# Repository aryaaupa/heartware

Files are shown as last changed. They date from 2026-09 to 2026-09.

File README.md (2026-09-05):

# heartware ♥

Heartware is being developed as a custom PCB with real-time audio playback, programmable lighting, sensing, battery power, and low-power firmware. The physical gift is intended to play a user-supplied local copy of **“The Man Who Can't Be Moved” by The Script**; the copyrighted recording is intentionally **not** distributed in this repository. This project will be used to demonstrate basic engineering principles to high schoolers. 

## Project goals

- Heart-shaped custom PCB with the electronics integrated into the board
- ESP32-S3-class embedded controller
- I²S digital audio path and Class-D speaker amplifier
- Local audio playback from flash storage
- Addressable RGB LED perimeter with audio-reactive animation
- Capacitive-touch interaction
- IMU-based pick-up / motion wake behavior
- Li-ion/LiPo battery, charging, battery monitoring, and USB-C power
- Hardware power switch and low-power states
- Debug/test points for board bring-up
- KiCad design sources, BOM, manufacturing outputs, firmware, and validation documentation

## Repository structure

```text
hardware/        KiCad board and schematic sources
firmware/        Embedded firmware and audio pipeline
manufacturing/   BOM / fabrication documentation
docs/            Architecture, bring-up, and validation notes
assets/private/  LOCAL-ONLY audio assets; ignored by Git
```

## Audio asset policy

The public repository contains no copyrighted song recording. A locally obtained audio file can be placed at:

```text
assets/private/song.wav
```

That directory is excluded by `.gitignore`. The firmware/build pipeline will be developed to preprocess and embed or stream the local asset without committing it.

## Status

**Rev A** is the initial KiCad prototype and uses a simpler XIAO ESP32-C3 + I²S amplifier architecture. **Rev B** is the planned advanced redesign described above and will replace the prototype architecture before fabrication.

> Do not fabricate Rev A yet. Footprints, power design, battery circuitry, audio chain, and Rev B architecture still require design review and DRC/ERC validation.

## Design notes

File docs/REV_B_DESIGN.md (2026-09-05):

# Heartware Rev B

Rev B turns the original musical-heart idea into a portable embedded system rather than an LED novelty board.

## Product behavior

The physical slide switch is the hard master power control. When switched on, the board performs a short warm-light boot animation and waits. Touching the central copper heart starts or stops the locally installed song. Twelve perimeter RGB LEDs animate from a precomputed audio-energy envelope so the light behavior follows the recording without spending MCU time on real-time FFT processing. Picking the heart up can wake a dim idle glow through the accelerometer, but motion never starts the song automatically.

## Hardware stack

- XIAO ESP32-S3 controller for MP3 decoding, I2S, capacitive touch, USB debug and LED control.
- MAX98357A I2S Class-D amplifier driving a 4-8 ohm miniature speaker.
- LIS3DH 3-axis accelerometer for pick-up/wake interaction.
- Twelve SK6812MINI-E RGB LEDs on the visible front perimeter.
- MCP73871 power-path charger so the LiPo can charge while the downstream product rail is physically switched off.
- TPS63031 buck-boost regulator for a stable 3.3 V logic rail across a 1-cell LiPo discharge curve.
- USB-C charge input, protected 1S LiPo, master slide switch and labeled test pads.

The board is specified as 4-layer, about 86 mm wide, with a 1.2 mm substrate. Front-facing electronics are limited to the LEDs and copper touch artwork; the controller, audio and power components live on the back.

## Why this is portfolio-grade

The repo is intended to show system architecture, PCB design, power-path reasoning, digital audio, embedded filesystem use, offline signal processing, capacitive interaction, motion sensing, low-power behavior, fabrication planning, and hardware bring-up. The audio preprocessing tool produces both a compressed local playback file and a synchronized amplitude envelope, while intentionally keeping the copyrighted recording outside Git history.

## Fabrication status

Rev B is an **engineering prototype**, not yet a released Gerber package. The placement and routing intent are implemented in KiCad, but exact fine-pitch footprints and manufacturer-specific land patterns must be audited against current datasheets before fabrication. Run KiCad ERC/DRC and complete the checklist in `docs/BRINGUP.md` before generating manufacturing outputs.

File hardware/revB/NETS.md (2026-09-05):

# Heartware Rev B signal plan

## MCU allocation

| Function | XIAO ESP32-S3 pin | Net |
|---|---|---|
| Capacitive heart electrode | D0 | `TOUCH` |
| RGB LED chain | D1 | `LED_DATA` |
| I2S bit clock | D2 | `I2S_BCLK` |
| I2S word select | D3 | `I2S_WS` |
| I2S PCM data | D4 | `I2S_DOUT` |
| I2C data | D5 | `I2C_SDA` |
| I2C clock | D6 | `I2C_SCL` |
| IMU interrupt | D7 | `IMU_INT` |

## Power domains

`VBUS_5V` is USB-C charging input only. `BAT+` is the protected 1S LiPo. The MCP73871 creates `SYS_RAW`; the slide switch creates the downstream switched rail `LED_PWR`. TPS63031 derives `3V3` for logic. The amplifier and RGB LEDs use the switched raw rail so their peak current does not pass through the 3.3 V regulator.

## Layout rules

Keep the ESP32 antenna region free of copper, battery, speaker magnet, and ground pour. Keep the I2S traces short and referenced to ground. Route speaker outputs as a close differential pair and keep them away from the touch electrode. Give each RGB LED a local 0.1 uF decoupler in the fabrication revision. The center touch electrode should have a ground keepout beneath and around it to preserve sensitivity.

## Important Rev B gate

The PCB contains deliberate prototype footprints so the mechanical composition, subsystem placement, and routing intent are editable immediately in KiCad. **Do not order this revision until the exact vendor footprints are replaced or audited against current manufacturer land-pattern drawings and KiCad ERC/DRC passes.**

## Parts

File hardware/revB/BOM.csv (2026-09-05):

Ref | Qty | Part | Suggested MPN / family | Package / form | Purpose | Prototype note
U1 | 1 | ESP32-S3 controller | Seeed XIAO ESP32-S3 | module | MP3 decode, I2S, touch, LEDs, USB debug | Back-mounted, USB accessible at edge
U2 | 1 | I2S Class-D amplifier | MAX98357A module | module | Digital audio to speaker | Module keeps Rev B hand-assemblable
U3 | 1 | LiPo charger + power-path | MCP73871-2CCI/ML | QFN-20 4x4 | Charge/load sharing | Verify charger resistor values and thermal pad
U4 | 1 | 3.3V buck-boost | TPS63031DSK | WSON-10 2.5x2.5 | Stable 3.3V rail | Use recommended 2.2uH inductor and ceramics
U5 | 1 | 3-axis accelerometer | LIS3DH | LGA-16 3x3 | Pick-up wake, motion interaction | I2C + INT1
D1-D12 | 12 | Addressable RGB LED | SK6812MINI-E | 3535 reverse/mini family | Perimeter animations | Confirm exact pin orientation before assembly
J1 | 1 | USB-C receptacle | USB2.0 Type-C power-only family | mid-mount or top-mount | Charging input | Add 5.1k CC1/CC2 Rd resistors
J2 | 1 | LiPo connector | JST-PH-2 vertical/right-angle | 2-pin | 1S LiPo | Mark polarity on silk + copper
J3 | 1 | Speaker connector | JST-PH-2 or solder pads | 2-pin | 4-8 ohm speaker | Keep output pair short
SW1 | 1 | Slide switch | SPDT SMD low-profile | SMD | Master system power | Placed at lower-left edge
SPK1 | 1 | Mini speaker | 8 ohm 1W 28-40mm | off-board | Audio output | Mount behind board or in printed stand
BAT1 | 1 | Protected LiPo | 1S 3.7V 500-1000mAh | off-board | Portable power | Use protected cell for first build

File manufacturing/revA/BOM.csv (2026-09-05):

Ref | Qty | Part | Suggested specification | Notes
U1 | 1 | Seeed Studio XIAO ESP32-C3 | 21 x 17.8 mm | MCU / flash / USB programming
U2 | 1 | MAX98357A I2S amplifier breakout | 3-5 V, mono class-D | Verify 7-pin order before assembly
D1-D5 | 5 | Warm-white LED | 3 mm through-hole | Front-facing
R1-R5 | 5 | Resistor | 220 ohm 0805 | LED current limiting
R6-R7 | 2 | Resistor | 5.1k 0805 | USB-C CC pull-down
D6 | 1 | Schottky diode | SS14 SOD-123 | Power isolation
SW1 | 1 | SPST slide switch | 2-pin / ~4 mm pad spacing | Verify footprint
J1 | 1 | USB-C receptacle | 16-pin USB2/power style | Verify exact receptacle footprint
SPK | 1 | Speaker | 8 ohm 0.5-1 W, 28-40 mm | Connect to U2 breakout

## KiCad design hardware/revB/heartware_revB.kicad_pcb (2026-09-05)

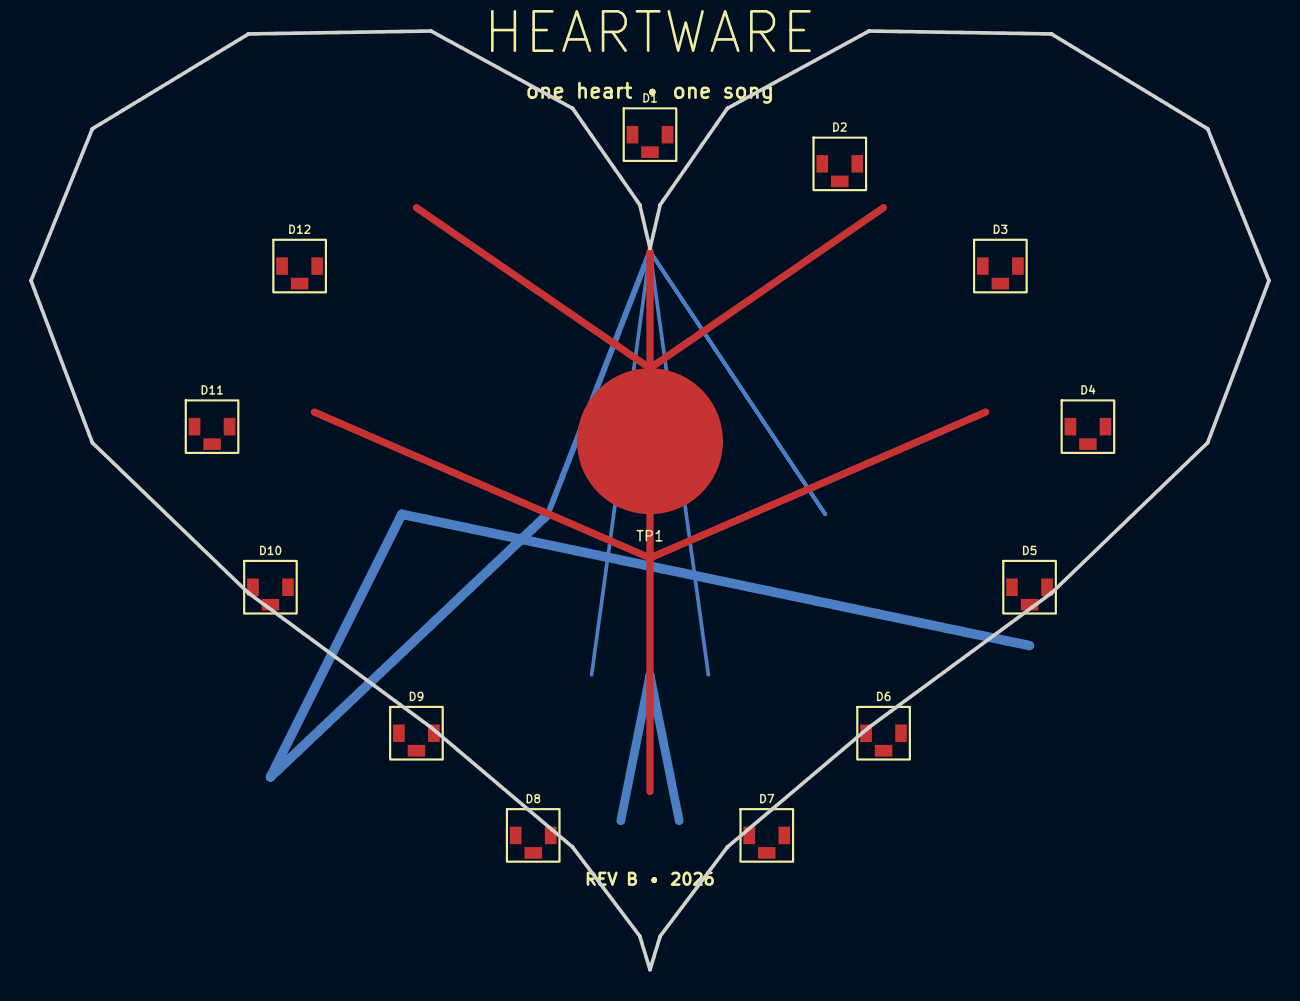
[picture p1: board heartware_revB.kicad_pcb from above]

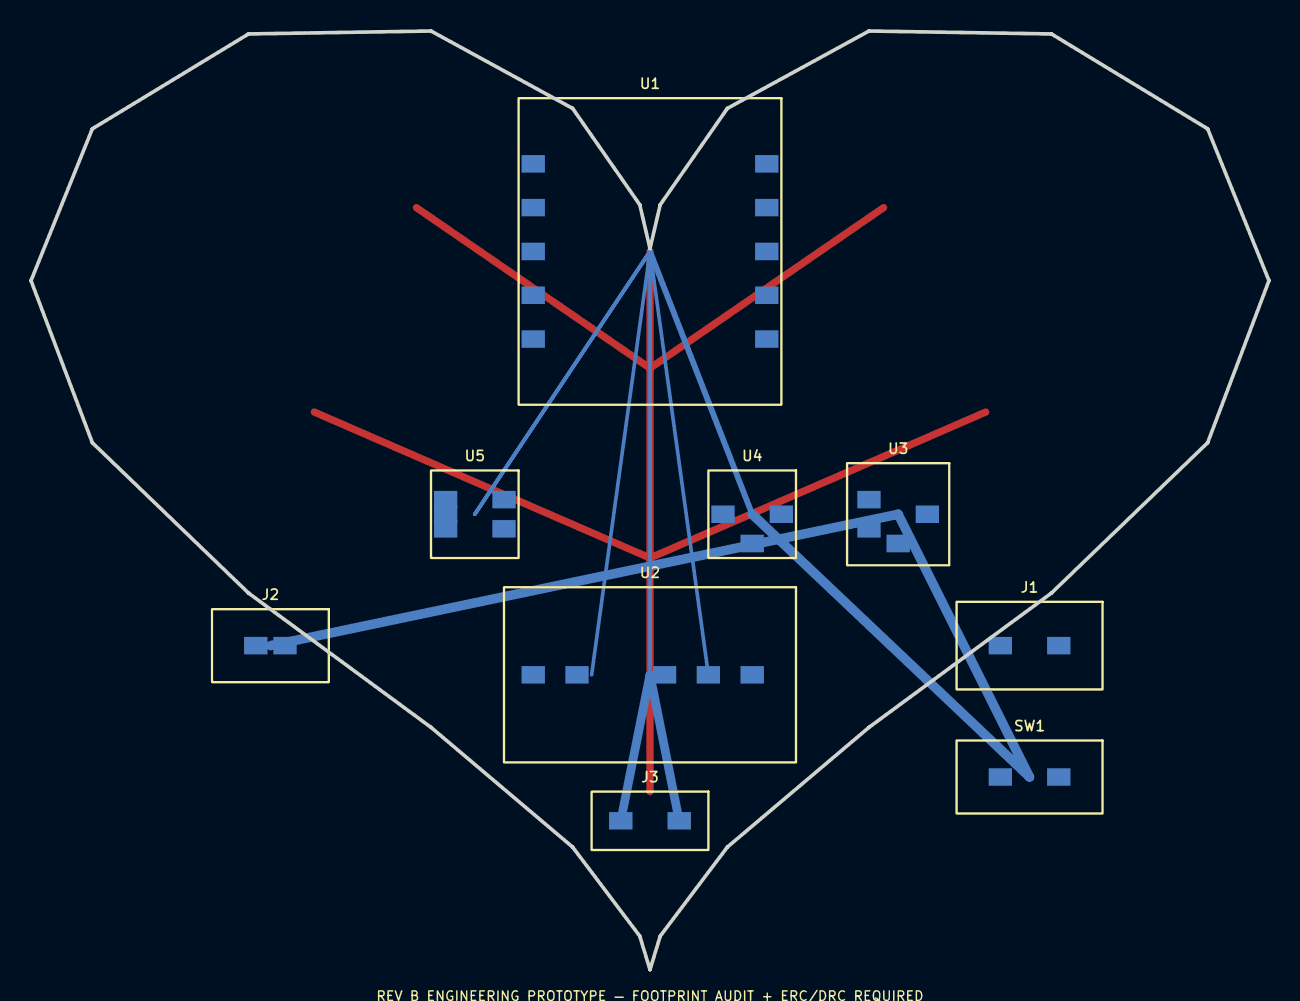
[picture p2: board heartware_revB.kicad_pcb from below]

Board: 4 copper layers, 84.8 x 64.3 mm, 22 parts (9 on the bottom side), 14 nets.

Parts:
D1: D1
D2: D2
D3: D3
D4: D4
D5: D5
D6: D6
D7: D7
D8: D8
D9: D9
D10: D10
D11: D11
D12: D12
J1: USB-C CHARGE; J1
J2: LIPO; J2
J3: SPEAKER; J3
SW1: POWER; SW1
TP1: TOUCH
U1: XIAO ESP32-S3; U1
U2: MAX98357A; U2
U3: MCP73871; U3
U4: TPS63031; U4
U5: LIS3DH; U5

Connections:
3V3: U1.3V3, U4.3V3, U5.3V3
BAT+: J2.+, U3.BAT
GND: D1.G, D2.G, D3.G, D4.G, D5.G, D6.G, D7.G, D8.G, D9.G, D10.G, D11.G, D12.G, J1.G, J2.-, U1.GND, U2.GND, U3.G, U4.G, U5.G
I2C_SCL: U1.SCL, U5.SCL
I2C_SDA: U1.SDA, U5.SDA
I2S_BCLK: U1.BCLK, U2.BCLK
I2S_DOUT: U1.DOUT, U2.DIN
I2S_WS: U1.WS, U2.WS
IMU_INT: U1.INT, U5.INT
LED_DATA: D1.D, D2.D, D3.D, D4.D, D5.D, D6.D, D7.D, D8.D, D9.D, D10.D, D11.D, D12.D, U1.LED
LED_PWR: D1.V, D2.V, D3.V, D4.V, D5.V, D6.V, D7.V, D8.V, D9.V, D10.V, D11.V, D12.V, SW1.OUT, U2.VIN, U4.IN
SYS_RAW: SW1.IN, U3.OUT
TOUCH: TP1.1, U1.TOUCH
VBUS_5V: J1.5V, U3.IN

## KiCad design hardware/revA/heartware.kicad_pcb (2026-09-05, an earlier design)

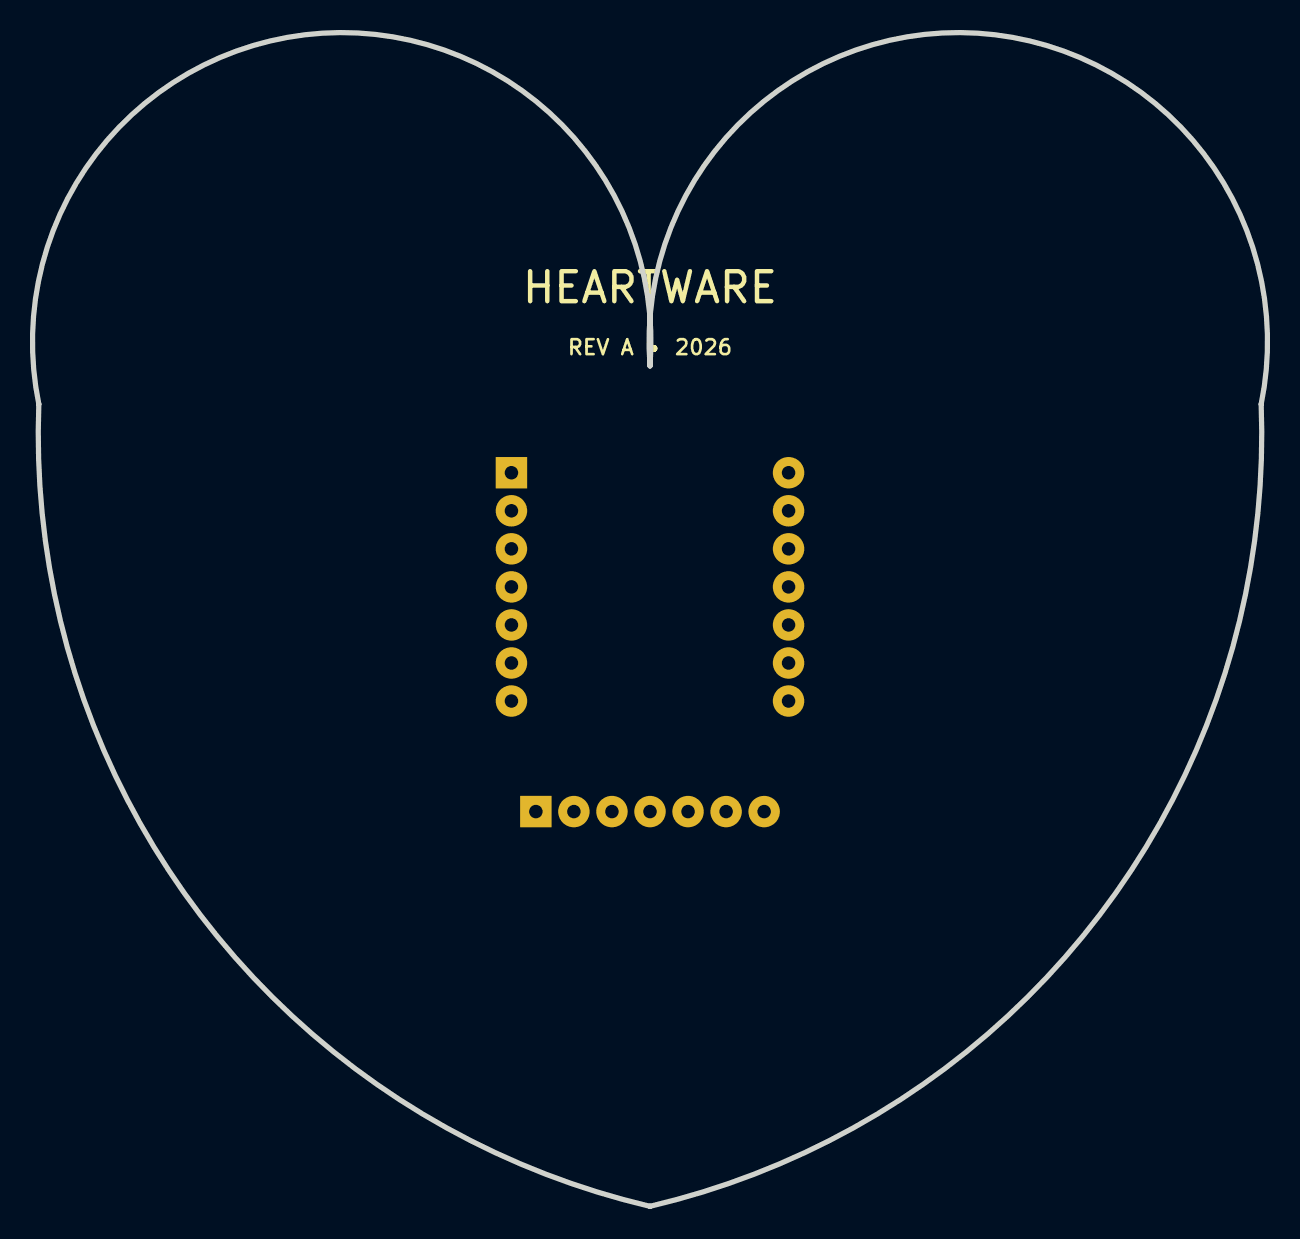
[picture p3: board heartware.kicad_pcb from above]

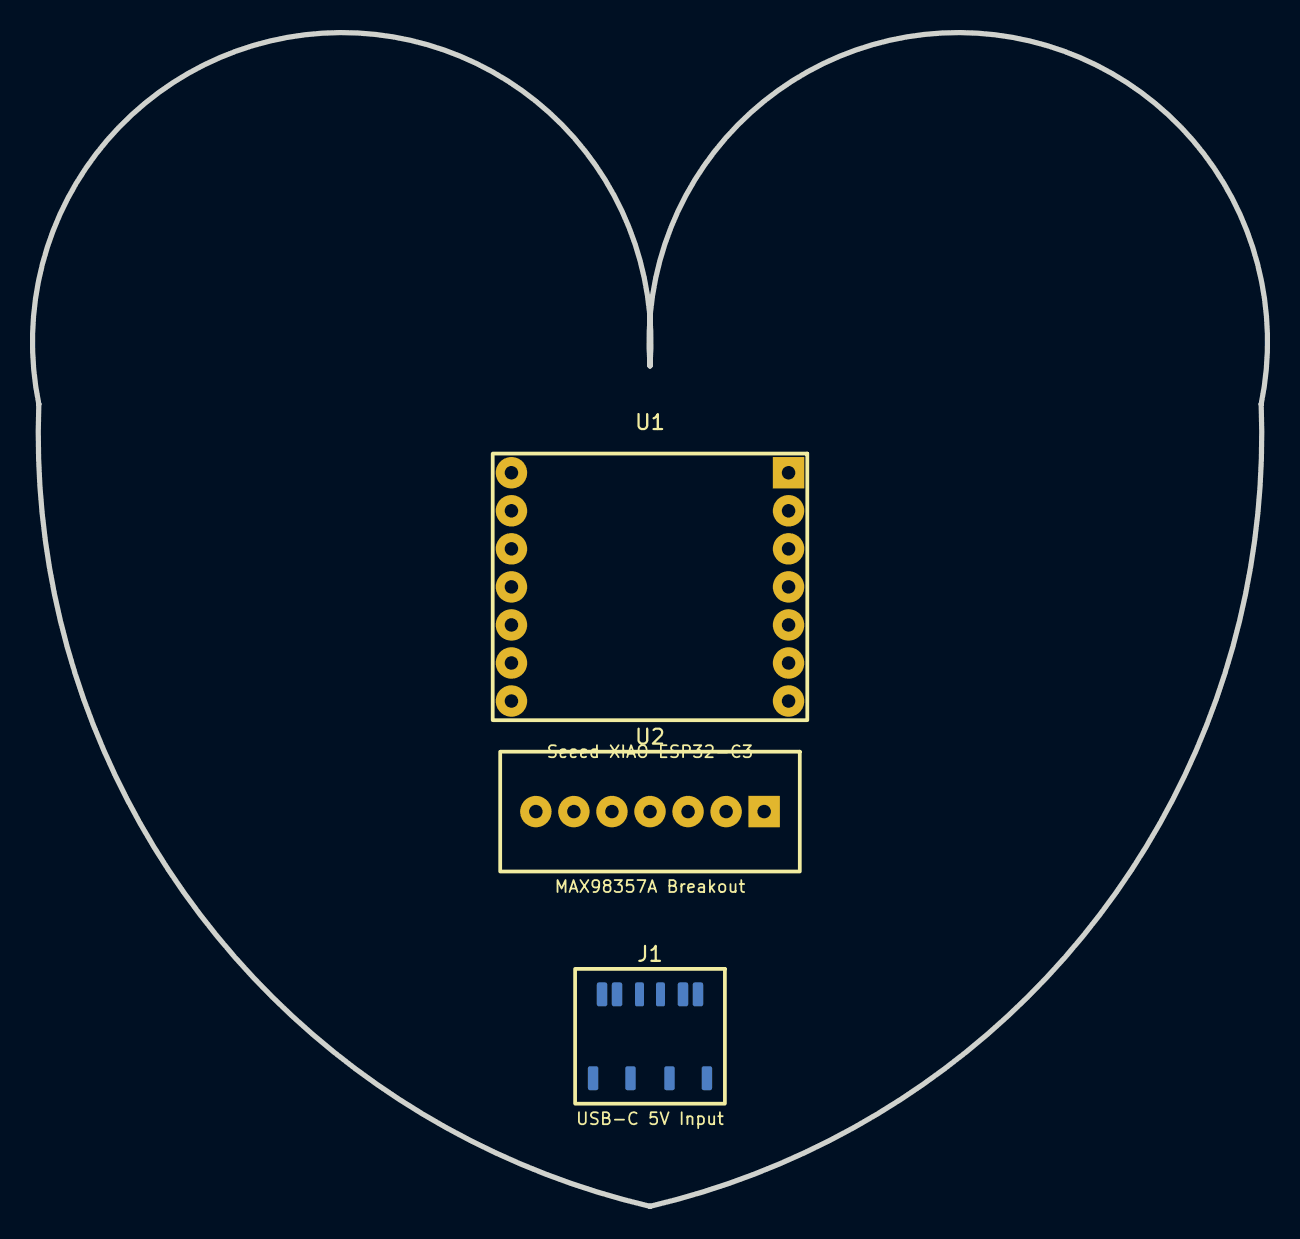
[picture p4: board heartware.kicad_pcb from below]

Board: 2 copper layers, 82.4 x 78.4 mm, 3 parts (3 on the bottom side), 6 nets, no tracks yet.

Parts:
J1: USB-C 5V Input; USB_C_POWER_ONLY
U1: Seeed XIAO ESP32-C3; XIAO_ESP32C3
U2: MAX98357A Breakout; MAX98357A_BREAKOUT

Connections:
5V_SYS: U1.14, U2.7
GND: J1.A1, J1.A12, J1.B1, J1.B12, U1.13, U2.6
I2S_BCLK: U1.7, U2.2
I2S_DIN: U1.8, U2.3
I2S_LRC: U1.6, U2.1
VBUS_IN: J1.A4, J1.A9, J1.B4, J1.B9

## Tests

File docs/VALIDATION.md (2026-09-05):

# Validation log

This file is intentionally blank until physical hardware exists. Do not replace measurements with simulations.

| Test | Method | Expected | Measured | Pass? |
|---|---|---:|---:|---|
| 3.3 V rail | DMM, battery 3.4-4.2 V | 3.3 V +/-3% | TBD | TBD |
| Idle current | DMM / source readback | TBD after firmware tune | TBD | TBD |
| Playback current | representative song at nominal volume | below power-path limit | TBD | TBD |
| LED peak current | full-white capped brightness | firmware-limited | TBD | TBD |
| Charge current | USB-C 5 V | per selected PROG value | TBD | TBD |
| Touch response | 50 trials | >95% intended activation | TBD | TBD |
| Pick-up wake | 50 trials | >95% intended wake | TBD | TBD |
| Audio dropout | full song | none | TBD | TBD |

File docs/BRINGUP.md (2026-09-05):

# Rev B bring-up and release gate

Do not connect a LiPo until power-path checks 1-7 pass.

1. Audit J1 USB-C footprint, shell tabs, CC1/CC2 5.1 kOhm pull-downs and VBUS polarity.
2. Audit MCP73871 QFN-20 land pattern, exposed pad, PROG resistor, charge current and system/battery routing against the current datasheet.
3. Audit TPS63031 WSON-10 footprint, inductor value/current rating, input/output capacitor placement and thermal pad.
4. Audit LIS3DH LGA orientation, I2C address strap and INT1 routing.
5. Confirm SK6812MINI-E orientation on all 12 positions and add one 0.1 uF local bypass capacitor per LED in the fabrication revision.
6. Confirm XIAO ESP32-S3 physical orientation, antenna keepout and access to its USB connector for firmware recovery.
7. Confirm speaker connector polarity and that MAX98357A output traces are isolated from the touch electrode and IMU.
8. Run KiCad ERC and DRC with the intended fab-house rules. No unconnected critical nets, copper-to-edge errors, antenna copper, or accidental mask slivers.
9. Power from a current-limited bench supply first. Verify 3.3 V before installing U1, U2 or the LiPo.
10. Populate MCU only; flash a GPIO/serial smoke test. Then add IMU, then one RGB LED, then the full LED chain, then amplifier and speaker.
11. Measure idle current, LED peak current, playback current and charge current. Record results in `docs/VALIDATION.md`.
12. Only after electrical bring-up succeeds should Gerbers/BOM/CPL be tagged as a fabrication release.

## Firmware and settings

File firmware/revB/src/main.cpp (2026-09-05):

#include <Arduino.h>
#include <Wire.h>
#include <LittleFS.h>
#include <Adafruit_NeoPixel.h>
#include <Adafruit_LIS3DH.h>
#include <AudioFileSourceLittleFS.h>
#include <AudioGeneratorMP3.h>
#include <AudioOutputI2S.h>
#include "song_envelope.h"

constexpr uint8_t PIN_TOUCH = D0;
constexpr uint8_t PIN_LED = D1;
constexpr uint8_t PIN_BCLK = D2;
constexpr uint8_t PIN_LRCLK = D3;
constexpr uint8_t PIN_DOUT = D4;
constexpr uint8_t PIN_SDA = D5;
constexpr uint8_t PIN_SCL = D6;
constexpr uint8_t PIN_IMU_INT = D7;
constexpr size_t LED_COUNT = 12;
constexpr uint16_t TOUCH_DEBOUNCE_MS = 450;
constexpr uint32_t IDLE_DIM_MS = 15000;

Adafruit_NeoPixel pixels(LED_COUNT, PIN_LED, NEO_GRB + NEO_KHZ800);
Adafruit_LIS3DH lis;
AudioGeneratorMP3 *mp3 = nullptr;
AudioFileSourceLittleFS *file = nullptr;
AudioOutputI2S *audioOut = nullptr;

bool playing = false;
uint32_t playbackStartMs = 0;
uint32_t lastTouchMs = 0;
uint32_t lastInteractionMs = 0;

static uint32_t warmColor(uint8_t level, uint8_t phase) {
  uint8_t r = level;
  uint8_t g = (uint16_t(level) * (55 + (phase % 20))) / 255;
  uint8_t b = (uint16_t(level) * 18) / 255;
  return pixels.Color(r, g, b);
}

static void renderEnvelope(uint8_t energy) {
  const float norm = energy / 255.0f;
  const uint8_t lit = 1 + uint8_t(norm * (LED_COUNT - 1));
  const uint8_t base = 10 + uint8_t(norm * 150);
  for (size_t i = 0; i < LED_COUNT; ++i) {
    uint8_t distance = abs(int(i) - int((millis() / 90) % LED_COUNT));
    uint8_t shimmer = (distance < 2) ? 35 : 0;
    uint8_t intensity = (i < lit) ? min(255, base + shimmer) : 4;
    pixels.setPixelColor(i, warmColor(intensity, i));
  }
  pixels.show();
}

static void allOff() {
  pixels.clear();
  pixels.show();
}

static void stopSong() {
  if (mp3) mp3->stop();
  playing = false;
  allOff();
}

static bool startSong() {
  stopSong();
  if (!LittleFS.exists("/song.mp3")) {
    Serial.println("No /song.mp3 in LittleFS. Run tools/prepare_audio.py locally, then uploadfs.");
    return false;
  }
  delete mp3;
  delete file;
  delete audioOut;
  mp3 = new AudioGeneratorMP3();
  file = new AudioFileSourceLittleFS("/song.mp3");
  audioOut = new AudioOutputI2S();
  audioOut->SetPinout(PIN_BCLK, PIN_LRCLK, PIN_DOUT);
  audioOut->SetGain(0.34f);
  if (!mp3->begin(file, audioOut)) return false;
  playbackStartMs = millis();
  lastInteractionMs = millis();
  playing = true;
  return true;
}

static void bootAnimation() {
  for (size_t i = 0; i < LED_COUNT; ++i) {
    pixels.setPixelColor(i, warmColor(80, i));
    pixels.show();
    delay(35);
  }
  delay(120);
  allOff();
}

static bool touched() {
  static uint32_t baseline = 0;
  uint32_t v = touchRead(PIN_TOUCH);
  if (baseline == 0) baseline = v;
  baseline = (baseline * 31 + v) / 32;
  bool active = (v + max<uint32_t>(8, baseline / 7)) < baseline;
  if (active && millis() - lastTouchMs > TOUCH_DEBOUNCE_MS) {
    lastTouchMs = millis();
    return true;
  }
  return false;
}

void setup() {
  Serial.begin(115200);
  delay(250);
  pixels.begin();
  pixels.setBrightness(180);
  allOff();

  Wire.begin(PIN_SDA, PIN_SCL);
  pinMode(PIN_IMU_INT, INPUT);
  if (lis.begin(0x18, &Wire) || lis.begin(0x19, &Wire)) {
    lis.setRange(LIS3DH_RANGE_4_G);
    lis.setDataRate(LIS3DH_DATARATE_10_HZ);
    Serial.println("LIS3DH online");
  } else {
    Serial.println("LIS3DH not detected; audio/touch still available");
  }

  if (!LittleFS.begin(true)) Serial.println("LittleFS mount failed");
  bootAnimation();
  lastInteractionMs = millis();
}

void loop() {
  if (touched()) {
    if (playing) stopSong();
    else startSong();
  }

  if (playing && mp3) {
    if (mp3->isRunning()) {
      if (!mp3->loop()) stopSong();
      uint32_t elapsedMs = millis() - playbackStartMs;
      uint32_t idx = (uint64_t(elapsedMs) * SONG_ENV_HZ) / 1000ULL;
      uint8_t e = idx < SONG_ENV_LEN ? SONG_ENV[idx] : 32;
      renderEnvelope(e);
    } else {
      stopSong();
    }
  } else if (millis() - lastInteractionMs > IDLE_DIM_MS) {
    allOff();
  }

  if (!playing && digitalRead(PIN_IMU_INT)) {
    lastInteractionMs = millis();
    for (size_t i = 0; i < LED_COUNT; ++i) pixels.setPixelColor(i, warmColor(18, i));
    pixels.show();
  }

  delay(2);
}

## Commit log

2026-09-05 Add private audio and KiCad ignore rules
2026-09-05 Add Rev A KiCad project
2026-09-05 Add Rev A schematic source
    [heartware.sch]
2026-09-05 Add Rev A heart-shaped PCB source
    [heartware.kicad_pcb]
2026-09-05 Add Rev A firmware prototype
2026-09-05 Add Rev A bill of materials
    [BOM.csv]
2026-09-05 Add Rev B bill of materials
    [BOM.csv]
2026-09-05 Add Rev B KiCad schematic source
    [heartware_revB.sch]
2026-09-05 Add Rev B KiCad project file
2026-09-05 Add Heartware Rev B KiCad PCB layout
    [heartware_revB.kicad_pcb]
2026-09-05 Add Rev B audio, touch, IMU and LED firmware
